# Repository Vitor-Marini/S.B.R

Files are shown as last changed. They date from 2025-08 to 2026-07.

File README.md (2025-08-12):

#S.B.R - Self Balance Robot

**Robô autoequilibrante com controle PID**

---

##  Descrição

Este projeto tem como objetivo o desenvolvimento de um robô autoequilibrante , que utiliza um controle PID para se manter estável sobre duas rodas. O sistema utiliza dados de um sensor giroscópio para calcular os ajustes de equilíbrio em tempo real.

Uma interface web interativa será servida diretamente pelo robô, permitindo visualizar os dados de controle (como ângulo, correção do PID e status do motor).

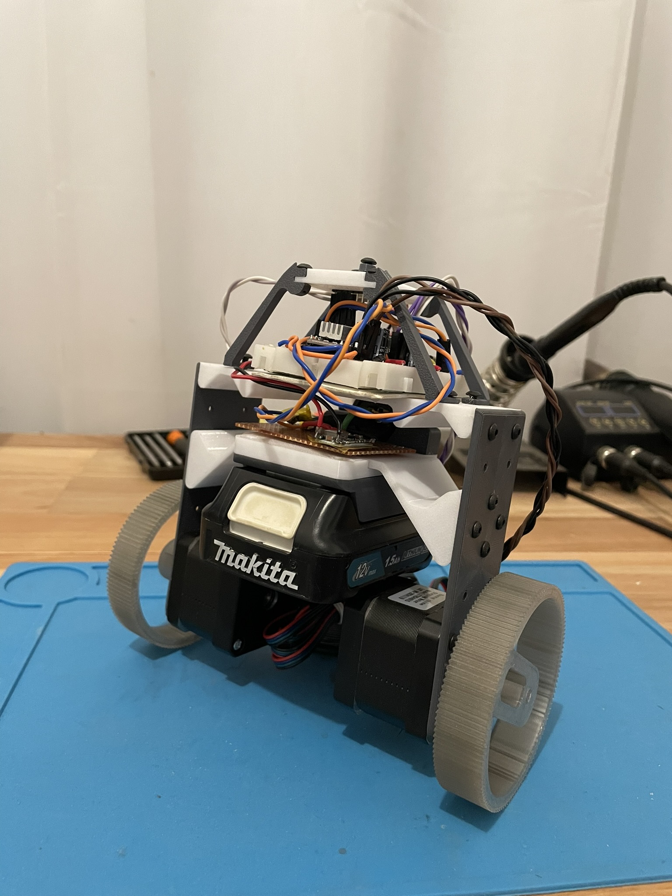
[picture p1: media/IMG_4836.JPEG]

---

## 🔧Componentes & Technologias

- **ESP32-C3 Supermini**
- **Motor de passo NEMA17 + DRV8825**
- **MPU6050 (giroscópio + acelerômetro)**
- **Bateria(12v) Makita BL1016
- **PlatformIO + C++**

- **Chassi 3D:** 
[3D models](hardware\3d-models)

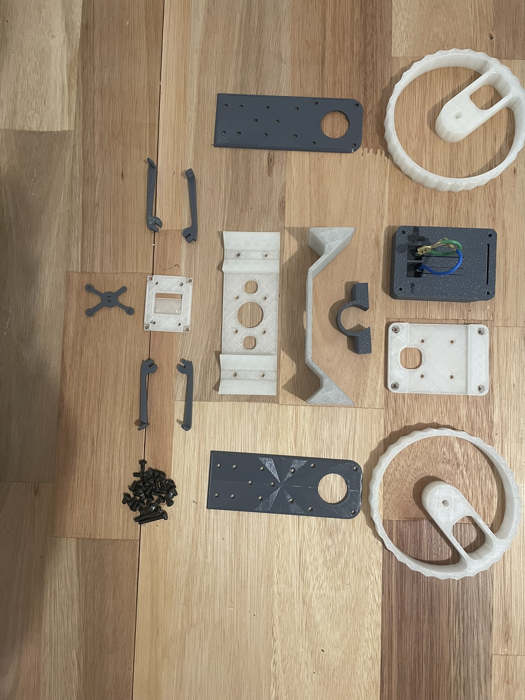
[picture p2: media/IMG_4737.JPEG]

---

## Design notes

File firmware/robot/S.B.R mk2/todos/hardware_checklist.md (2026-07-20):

# Hardware Checklist — S.B.R mk2

Tarefas físicas para preparar o robô para o novo firmware.

---

## 1. Medir o diâmetro das rodas

- [ ] Medir o diâmetro externo da roda em **milímetros**
- [ ] Anotar o valor em `config.hpp` como `WHEEL_DIAMETER_MM`
- Necessário para odometria e futura velocidade linear

---

## 2. Descobrir o microstepping dos DRV8825

Os pinos M0, M1, M2 dos drivers **não estão conectados ao ESP32-C3**.  
Eles estão configurados via jumpers/solda nos próprios módulos DRV8825.

- [ ] Inspecionar fisicamente os dois drivers DRV8825
- [ ] Verificar se há jumpers (shunts) em M0, M1, M2
- [ ] Se não houver jumpers: provavelmente **full step** (200 passos/volta)
- [ ] Anotar a configuração e o steps_per_rev resultante

Tabela de configuração típica (DRV8825):

| M2  | M1  | M0  | Microstepping | Steps/rev |
|-----|-----|-----|---|---|
| LOW | LOW | LOW | Full step | 200 |
| LOW | LOW | HIGH| 1/2 step | 400 |
| LOW | HIGH| LOW | 1/4 step | 800 |
| LOW | HIGH| HIGH| 1/8 step | 1600 |
| HIGH| LOW | LOW | 1/16 step | 3200 |
| HIGH| LOW | HIGH| 1/32 step | 6400 |

Valores típicos para jumpers abertos (sem shunt): todos LOW = **full step**.

---

## 3. Verificar ENABLE dos DRV8825

- [ ] Verificar se o pino ENABLE de cada DRV8825 está com pull-up ou pull-down
- [ ] Se pino ENABLE solto: o módulo tem pull-up interno → motor habilitado
- [ ] Se pino ENABLE conectado ao GND via resistor: motor sempre habilitado
- [ **Ideal:** Conectar ENABLE a um GPIO do ESP32-C3 para desligar motores em IDLE/FAULT

Se não for possível conectar ao ESP32, deixar ENABLE como está (sempre habilitado).

---

## 4. Definir o sentido de rotação dos motores

- [ ] Alimentar o motor esquerdo com DIR=HIGH e verificar se a roda gira para **frente** (robô anda para frente)
- [ ] Se não: anotar que o motor esquerdo precisa de DIR invertido (`MOTOR_LEFT_REVERSED = true` no config)
- [ ] Repetir para o motor direito
- [ ] Atualizar `MOTOR_LEFT_REVERSED` e `MOTOR_RIGHT_REVERSED` no `config.hpp`

---

## 5. Verificar tensão de referência dos DRV8825 (corrente do motor)

- [ ] Medir a tensão no potenciômetro de cada DRV8825 (VREF)
- [ ] A corrente máxima do motor NEMA17 é tipicamente 1.0-1.5A
- [ ] VREF ideal ≈ 0.7V a 1.2V (depende do resistor sense)
- [ ] Fórmula: I_max = VREF × 2 (para DRV8825 com resistor sense de 0.1Ω)

---

## 6. Nivelamento físico

- [ ] Verificar se o MPU6050 está montado nivelado (paralelo ao chão)
- [ ] Se não estiver nivelado, anotar o offset mecânico
- [ ] Verificar se as rodas estão bem fixas e alinhadas
- [ ] Verificar se o centro de massa está acima do eixo das rodas (ou ligeiramente atrás)

---

## 7. Bateria

- [ ] Bateria Makita BL1016 (10.8V/12V) — verificar tensão nominal
- [ ] Verificar se há divisor de tensão para monitoramento pela ADC do ESP32-C3
- [ ] Se houver, anotar os resistores do divisor (R1, R2) para configurar no firmware

---

## 8. Teste de LEDC PWM (pré-balanceamento)

Após gravar o firmware mk2 pela primeira vez:

- [ ] Conectar via Serial (115200 baud)
- [ ] Digitar `motor left 500` — o motor esquerdo deve girar a 500 steps/s
- [ ] Digitar `motor right 500` — o motor direito deve girar a 500 steps/s
- [ ] Digitar `motor left 0` — o motor esquerdo deve parar
- [ ] Verificar se o sentido está correto (usar `motor left -500` para inverter)

---

## Configuração da RoboCORE (preencher após medir)

```cpp
// Em include/config.hpp
WHEEL_DIAMETER_MM =  // <-- preencher
STEPS_PER_REV =      // <-- preencher (200 × microstepping)
MOTOR_LEFT_REVERSED  = false  // <-- ajustar se necessário
MOTOR_RIGHT_REVERSED = false  // <-- ajustar se necessário
```

---

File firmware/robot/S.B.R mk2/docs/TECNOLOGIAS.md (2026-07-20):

# Tecnologias e Técnicas — S.B.R mk2

## Controle de Motores com LEDC PWM (sem interrupções!)

No firmware original (mk1), os motores de passo eram controlados por interrupções de hardware
(timers). Cada pulso de passo gerava uma interrupção que chamava `digitalWrite()` dentro da ISR
— extremamente custoso para um microcontrolador de núcleo único (ESP32-C3).

No mk2, usamos o periférico **LEDC** (PWM) do ESP32-C3:

- Cada motor recebe um canal PWM independente
- A **frequência do PWM = steps por segundo** do motor
- Duty cycle fixo em 50% (cada borda de subida = um passo do motor)
- **Zero interrupções** — o hardware gera os pulsos sozinho
- A CPU fica livre para rodar o controle e a telemetria

```
LEDC Timer 0 ── Canal 0 ── GPIO 0 (STEP motor esquerdo)
LEDC Timer 1 ── Canal 3 ── GPIO 3 (STEP motor direito)
```

Para mudar a velocidade, basta chamar `ledc_set_freq()`. Para parar o motor,
colocamos o duty cycle em 0 (pino fica em LOW). Não há mais a sobrecarga
de interrupções a cada passo.

### Rampa de aceleração

Toda mudança de velocidade passa por um **rampeador** que limita a aceleração:

```
maxDelta = maxAccelStepsS2 × dt
current += constrain(target - current, -maxDelta, +maxDelta)
```

Isso evita que os steppers percam passos por aceleração brusca.
O valor padrão é 25000 steps/s² (0 a 6000 steps/s em ~240ms),
configurável em `config.hpp` como `motor.maxAccelStepsS2`.

---

## Filtro Mahony (fusão de sensores)

O MPU6050 tem dois sensores:

| Sensor | Bom para | Ruim para |
|---|---|---|
| Acelerômetro | Saber onde é "pra baixo" (gravidade) | Ruído alto, não responde rápido |
| Giroscópio | Medir rotação rápida com precisão | Deriva com o tempo (drift) |

O **Filtro Mahony** combina o melhor dos dois:

1. Mede o ângulo pelo acelerômetro (referência de gravidade)
2. Estima o ângulo pelo giroscópio (resposta rápida)
3. Calcula o erro entre os dois
4. Usa esse erro para corrigir o giroscópio (estimando o bias/deriva)
5. Integra o giroscópio corrigido para obter o ângulo final

O resultado é um ângulo de pitch preciso e com baixo atraso, essencial para o
equilíbrio. O filtro também estima automaticamente o bias do girospcópio
enquanto o robô opera, eliminando a necessidade de recalibração constante.

### Parâmetros do filtro

- **Mahony Kp** (0.5): velocidade com que o filtro corrige o ângulo usando o
  acelerômetro. Maior = resposta mais rápida, mas mais ruído.
- **Mahony Ki** (0.001): velocidade com que o filtro aprende o bias do
  giroscópio. Muito alto pode causar oscilações.

Configuráveis em `config.hpp` como `filter.mahonyKp` e `filter.mahonyKi`.

### Filtro Complementar (fallback)

Se o Mahony se mostrar pesado demais, o firmware também tem um
**Filtro Complementar** clássico:

```
ângulo = α × (ângulo + gyro × dt) + (1 − α) × accelAngle
```

O alpha padrão é 0.98 (98% giroscópio, 2% acelerômetro).
Pode ser ativado via `imu.setUseMahony(false)`.

---

## PID Cascateado (três níveis de controle)

O controle de equilíbrio usa três malhas aninhadas, cada uma rodando em uma
frequência diferente:

```
┌─────────────────────────────────────────────────────┐
│                    Malha de Yaw                       │
│  (heading-hold) mantém o robô apontando na direção   │
│  yaw_correção = Kp_y × erro_yaw + Kd_y × (-yaw_rate) │
└─────────────────────┬───────────────────────────────┘
                      │ comando diferencial
                      ▼
┌─────────────────────────────────────────────────────┐
│                  Malha de Ângulo                      │
│  (equilíbrio) mantém o robô na vertical              │
│  torque = Kp_a × erro_angulo + Kd_a × (-pitch_rate)  │
└─────────────────────┬───────────────────────────────┘
                      │ torque total
                      ▼
┌─────────────────────────────────────────────────────┐
│              Distribuição para os Motores             │
│  motor_esquerdo = torque + yaw_correção              │
│  motor_direito  = torque − yaw_correção              │
└─────────────────────────────────────────────────────┘
```

### 1. Malha de Ângulo (100 Hz)

- **Entrada**: pitch do filtro Mahony + pitch rate do giroscópio
- **Saída**: torque (0 a 100%)
- **Controle**: PD com derivativo do gyro (não do ângulo)

```
torque = Kp × (setpoint − pitch) + Kd × (−pitch_rate)
```

Usar o gyro rate direto no termo derivativo elimina o ruído amplificado
que aconteceria ao derivar o ângulo.

Padrões: Kp = 25.0, Ki = 0.5, Kd = 0.8

### 2. Malha de Yaw (100 Hz)

- **Entrada**: yaw estimado pelo Mahony + yaw rate do giroscópio
- **Saída**: correção diferencial (−30 a +30%)
- **Controle**: PID

Mantém o robô apontando na mesma direção (heading-hold).
O erro de yaw é normalizado para ±180° para evitar saltos no controle.

Padrões: Kp = 2.0, Ki = 0.02, Kd = 0.5

### 3. Malha de Velocidade (futuro — implementação parcial)

Preparada para o "andar". Quando ativada:
- Entrada: odometria (contagem de passos)
- Saída: setpoint de ângulo (inclinar para frente = andar para frente)

O controle de velocidade ainda não está ativo — os placeholders existem
no `config.hpp` como `velocityPid` para quando você quiser implementar.

---

## Odometria (contagem de passos)

Cada motor tem um contador de passos acumulados:

```cpp
_leftSteps += (int32_t)(currentSpeedL × dt);
_rightSteps += (int32_t)(currentSpeedR × dt);
```

A partir disso, podemos calcular:
- **Distância percorrida**: `passos / stepsPorVolta × π × diametroRoda`
- **Velocidade linear**: derivada da distância
- **Rotação do robô**: diferença entre as rodas

A odometria é usada no controle de velocidade (futuro) e pode ser visualizada
no CLI com o comando `status`. Use `reset` para zerar os contadores.

**ATENÇÃO**: A odometria com steppers sem encoder é estimada — se o motor
perder passos (situação de stall), a contagem fica incorreta.

---

## Máquina de Estados (Supervisor)

O robô não tenta mais equilibrar imediatamente ao ligar. Agora ele segue
uma máquina de estados:

```
INIT ──→ CALIBRATE ──→ IDLE ──→ STARTING ──→ ACTIVE ──→ MOVING
                           ↑                        │
                           └──── FAULT ←────────────┘
```

| Estado | O que acontece |
|---|---|
| **INIT** | Inicializa MPU6050, configura filtros |
| **CALIBRATE** | Calibra o giroscópio (500 amostras, robô parado) |
| **IDLE** | Robô parado, WiFi ligado, só monitora ângulo |
| **STARTING** | Rampa de 2s: ganhos do PID crescem de 0 a 100% |
| **ACTIVE** | Equilíbrio ativo + heading-hold |
| **MOVING** | ACTIVE + controle de velocidade (futuro) |
| **FAULT** | Ângulo > 45°, motores desligados. Auto-recovery após 3s estável |

Isso evita que o robô "saia disparado" ao ligar e permite recuperação
automática de quedas.

---

## CLI (Terminal Interativo)

O terminal serial agora aceita comandos:

| Comando | Função |
|---|---|
| `start` | Inicia o balanceamento |
| `stop` | Para e volta a IDLE |
| `calibrate` | Recalibra o giroscópio |
| `status` | Mostra todos os parâmetros |
| `tune kp 30` | Ajusta Kp do ângulo em tempo real |
| `tune ykp 3` | Ajusta Kp do yaw |
| `tune sp 1` | Muda o setpoint (inclinação alvo) |
| `motor left 500` | Gira motor esquerdo a 500 steps/s |
| `motor right -300` | Gira motor direito ao contrário |
| `angle` | Mostra ângulo atual |
| `save` / `load` | Salva/carrega config na flash |
| `reset` | Zera odometria e integrais |

---

## Dashboard Web (WiFi + WebSocket)

O robô cria uma rede WiFi (`SBR_ROBOT`, senha `12345678`).

O dashboard web (`192.168.4.1`) mostra em tempo real:
- **Gráfico do ângulo** (Chart.js, últimos 100 pontos)
- **Estado atual** do robô (ACTIVE, FAULT, etc)
- Telemetria: pitch, rate, yaw, output do PID, velocidades
- **Sliders** para ajustar Kp, Ki, Kd, setpoint
- **Botões**: INICIAR, PARAR, CALIBRAR
- **Exportar CSV** dos dados de ângulo

A comunicação é via WebSocket — os dados do PID e telemetria são enviados
a ~10 Hz.

---

## MPU6050 — Configuração

| Parâmetro | Mk1 | Mk2 |
|---|-----|-----|
| Range acelerômetro | ±8G | ±8G |
| Range giroscópio | ±500°/s | ±500°/s |
| **DLPF (filtro hardware)** | **5 Hz** | **44 Hz** |

O DLPF de 5Hz no mk1 adicionava ~40ms de atraso na leitura, o que
desestabilizava o controle. No mk2, subimos para 44Hz e deixamos o
filtro Mahony cuidar do ruído restante — resposta muito mais rápida.

---

## Componentes e Pinagem

```
ESP32-C3 Supermini
├── GPIO 0  → STEP motor L (LEDC Canal 0)
├── GPIO 1  → DIR motor L
├── GPIO 2  → DIR motor R
├── GPIO 3  → STEP motor R (LEDC Canal 3)
├── GPIO 8  → SDA (MPU6050)
└── GPIO 9  → SCL (MPU6050)
```

Os pinos M0, M1, M2 (microstepping) e ENABLE dos DRV8825 não estão
conectados ao ESP32. O microstepping é definido por jumpers nos próprios
módulos. **Verifique a configuração atual** (provavelmente full step).

---

## Resumo das melhorias do mk1 para o mk2

| Problema no mk1 | Solução no mk2 |
|---|---|
| Stepper via ISR com digitalWrite (lento) | LEDC PWM sem interrupção |
| dt fixo de 10ms | dt medido em tempo real |
| Filtro complementar | Mahony com estimativa de bias |
| Sem controle de yaw | Heading-hold com PID |
| Inicialização abrupta | Máquina de estados com rampa |
| MPU6050 DLPF em 5Hz (lento) | DLPF em 44Hz |
| Ki = 0 (sem integral) | Ki = 0.5 com anti-windup |
| Só log serial | CLI interativo com comandos |
| Debug só por Serial | Dashboard Web + Serial CLI |

---

## Configuração Inicial (após montagem)

Antes de tentar equilibrar, complete os passos em
[`todos/hardware_checklist.md`](../todos/hardware_checklist.md):

1. Medir diâmetro das rodas → `wheel_diameter_mm`
2. Verificar microstepping → `steps_per_rev`
3. Testar sentido dos motores via CLI → `left_reversed` / `right_reversed`
4. Com `start`, observar se o robô tenta se equilibrar
5. Ajustar Kp, Ki, Kd pelos sliders do dashboard ou CLI (`tune`)

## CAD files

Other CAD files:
hardware/3d-models/CHASSI_Pcb_SHELF.f3d
hardware/3d-models/CHASSI_PowerSwitch_HOLDER.f3d
hardware/3d-models/CHASSI_SideFrame_LEFT.f3d
hardware/3d-models/CHASSI_SideFrame_RIGHT.f3d
hardware/3d-models/CHASSI_mpu_HOLDER.f3d
hardware/3d-models/LINK-SHELF-to-B_ADPTOR.f3d
hardware/3d-models/Wheel Big.f3d
hardware/3d-models/Whell Medium.f3d
hardware/3d-models/makita_10.8v_v38 v10.f3d

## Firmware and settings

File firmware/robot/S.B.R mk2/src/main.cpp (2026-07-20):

#include <Arduino.h>
#include "config.hpp"
#include "motor.hpp"
#include "imu_manager.hpp"
#include "balance.hpp"
#include "supervisor.hpp"
#include "web_interface.hpp"
#include "cli.hpp"

void setup() {
    Serial.begin(115200);
    delay(500);
    Serial.println("\n\n=== S.B.R mk2 ===");

    cfg.begin();

    motors.begin();

    supervisor.begin();

    web.begin();

    cli.begin();
}

void loop() {
    supervisor.run();

    web.broadcast();

    cli.update();

    delay(1);
}

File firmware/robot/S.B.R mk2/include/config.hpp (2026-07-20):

#ifndef CONFIG_HPP
#define CONFIG_HPP

#include <Arduino.h>

struct PIDGains {
    float kp;
    float ki;
    float kd;
};

struct MotorParams {
    float stepsPerRev = 3200.0f;
    float wheelDiameterMm = 80.0f;
    float maxAccelStepsS2 = 25000.0f;
    bool leftReversed = false;
    bool rightReversed = false;
};

struct FilterParams {
    float mahonyKp = 0.5f;
    float mahonyKi = 0.001f;
    float complementaryAlpha = 0.98f;
};

class ConfigManager {
public:
    void begin();

    PIDGains anglePid{25.0f, 0.5f, 0.8f};
    PIDGains velocityPid{0.5f, 0.1f, 0.0f};
    PIDGains yawPid{2.0f, 0.02f, 0.5f};

    MotorParams motor;
    FilterParams filter;

    float setpoint = 0.0f;
    float failsafeAngle = 45.0f;

    float pitchAngle = 0.0f;
    float pitchRate = 0.0f;
    float yawAngle = 0.0f;
    float yawRate = 0.0f;
    float pidOutput = 0.0f;
    float leftSpeed = 0.0f;
    float rightSpeed = 0.0f;
    int robotState = 0;

    bool load();
    bool save();
    void print();
};

extern ConfigManager cfg;
#endif

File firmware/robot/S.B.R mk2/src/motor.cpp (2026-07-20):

#include "motor.hpp"
#include "config.hpp"
#include <driver/ledc.h>
#include <math.h>

MotorManager motors;

void MotorManager::begin() {
    pinMode(PIN_DIR_L, OUTPUT);
    pinMode(PIN_DIR_R, OUTPUT);
    digitalWrite(PIN_DIR_L, LOW);
    digitalWrite(PIN_DIR_R, LOW);

    ledc_timer_config_t tL = {
        .speed_mode = LEDC_LOW_SPEED_MODE,
        .duty_resolution = LEDC_TIMER_10_BIT,
        .timer_num = (ledc_timer_t)LEDC_TIM_L,
        .freq_hz = 1000,
        .clk_cfg = LEDC_AUTO_CLK
    };
    ledc_timer_config(&tL);

    ledc_timer_config_t tR = {
        .speed_mode = LEDC_LOW_SPEED_MODE,
        .duty_resolution = LEDC_TIMER_10_BIT,
        .timer_num = (ledc_timer_t)LEDC_TIM_R,
        .freq_hz = 1000,
        .clk_cfg = LEDC_AUTO_CLK
    };
    ledc_timer_config(&tR);

    ledc_channel_config_t chL = {
        .gpio_num = PIN_STEP_L,
        .speed_mode = LEDC_LOW_SPEED_MODE,
        .channel = (ledc_channel_t)LEDC_CH_L,
        .timer_sel = (ledc_timer_t)LEDC_TIM_L,
        .duty = 512,
        .hpoint = 0
    };
    ledc_channel_config(&chL);

    ledc_channel_config_t chR = {
        .gpio_num = PIN_STEP_R,
        .speed_mode = LEDC_LOW_SPEED_MODE,
        .channel = (ledc_channel_t)LEDC_CH_R,
        .timer_sel = (ledc_timer_t)LEDC_TIM_R,
        .duty = 512,
        .hpoint = 0
    };
    ledc_channel_config(&chR);

    ledc_set_freq(LEDC_LOW_SPEED_MODE, (ledc_timer_t)LEDC_TIM_L, 1);
    ledc_set_freq(LEDC_LOW_SPEED_MODE, (ledc_timer_t)LEDC_TIM_R, 1);

    _lastUpdate = millis();

    Serial.println("Motores inicializados (LEDC PWM).");
}

void MotorManager::_setChannelFreq(int timer, int channel, int pin, float stepsPerSec) {
    int freq = (int)(stepsPerSec + 0.5f);
    if (freq < 1) freq = 1;
    if (freq > 50000) freq = 50000;

    ledc_set_freq(LEDC_LOW_SPEED_MODE, (ledc_timer_t)timer, freq);
}

void MotorManager::_stopChannel(int channel, int pin) {
    ledc_set_duty(LEDC_LOW_SPEED_MODE, (ledc_channel_t)channel, 0);
    ledc_update_duty(LEDC_LOW_SPEED_MODE, (ledc_channel_t)channel);
}

void MotorManager::_rampMotor(float target, float& current, float maxDelta) {
    float delta = target - current;
    if (fabsf(delta) <= maxDelta) {
        current = target;
    } else {
        current += (delta > 0.0f) ? maxDelta : -maxDelta;
    }
}

void MotorManager::setSpeeds(float left, float right) {
    uint32_t now = millis();
    float dt = (now - _lastUpdate) / 1000.0f;
    if (dt > 0.1f || dt <= 0.0f) dt = 0.01f;
    _lastUpdate = now;

    int dirL = (left >= 0) ? HIGH : LOW;
    int dirR = (right >= 0) ? HIGH : LOW;

    if (cfg.motor.leftReversed) dirL = (dirL == HIGH) ? LOW : HIGH;
    if (cfg.motor.rightReversed) dirR = (dirR == HIGH) ? LOW : HIGH;

    digitalWrite(PIN_DIR_L, dirL);
    digitalWrite(PIN_DIR_R, dirR);

    float absL = fabsf(left);
    float absR = fabsf(right);

    float maxDelta = cfg.motor.maxAccelStepsS2 * dt;

    float targetL = absL;
    float targetR = absR;

    if (left == 0.0f && right == 0.0f) {
        _currentL = 0.0f;
        _currentR = 0.0f;
    } else {
        _rampMotor(targetL, _currentL, maxDelta);
        _rampMotor(targetR, _currentR, maxDelta);
    }

    if (_currentL < 10.0f) {
        ledc_set_duty(LEDC_LOW_SPEED_MODE, (ledc_channel_t)LEDC_CH_L, 0);
        ledc_update_duty(LEDC_LOW_SPEED_MODE, (ledc_channel_t)LEDC_CH_L);
    } else {
        ledc_set_duty(LEDC_LOW_SPEED_MODE, (ledc_channel_t)LEDC_CH_L, 512);
        ledc_update_duty(LEDC_LOW_SPEED_MODE, (ledc_channel_t)LEDC_CH_L);
        _setChannelFreq(LEDC_TIM_L, LEDC_CH_L, PIN_STEP_L, _currentL);
    }

    if (_currentR < 10.0f) {
        ledc_set_duty(LEDC_LOW_SPEED_MODE, (ledc_channel_t)LEDC_CH_R, 0);
        ledc_update_duty(LEDC_LOW_SPEED_MODE, (ledc_channel_t)LEDC_CH_R);
    } else {
        ledc_set_duty(LEDC_LOW_SPEED_MODE, (ledc_channel_t)LEDC_CH_R, 512);
        ledc_update_duty(LEDC_LOW_SPEED_MODE, (ledc_channel_t)LEDC_CH_R);
        _setChannelFreq(LEDC_TIM_R, LEDC_CH_R, PIN_STEP_R, _currentR);
    }

    _leftSteps += (int32_t)(_currentL * dt);
    _rightSteps += (int32_t)(_currentR * dt);

    cfg.leftSpeed = (dirL == HIGH) ? _currentL : -_currentL;
    cfg.rightSpeed = (dirR == HIGH) ? _currentR : -_currentR;
}

void MotorManager::stop() {
    _currentL = 0.0f;
    _currentR = 0.0f;
    ledc_set_duty(LEDC_LOW_SPEED_MODE, (ledc_channel_t)LEDC_CH_L, 0);
    ledc_update_duty(LEDC_LOW_SPEED_MODE, (ledc_channel_t)LEDC_CH_L);
    ledc_set_duty(LEDC_LOW_SPEED_MODE, (ledc_channel_t)LEDC_CH_R, 0);
    ledc_update_duty(LEDC_LOW_SPEED_MODE, (ledc_channel_t)LEDC_CH_R);
}

void MotorManager::enable() {
    stop();
}

void MotorManager::disable() {
    stop();
}

void MotorManager::resetOdometry() {
    _leftSteps = 0;
    _rightSteps = 0;
}

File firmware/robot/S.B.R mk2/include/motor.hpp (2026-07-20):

#ifndef MOTOR_HPP
#define MOTOR_HPP

#include <Arduino.h>

class MotorManager {
public:
    void begin();
    void setSpeeds(float leftSteps, float rightSteps);
    void stop();
    void enable();
    void disable();

    int32_t getLeftSteps() { return _leftSteps; }
    int32_t getRightSteps() { return _rightSteps; }
    void resetOdometry();

private:
    static const int PIN_STEP_L = 0;
    static const int PIN_DIR_L  = 1;
    static const int PIN_DIR_R  = 2;
    static const int PIN_STEP_R = 3;

    static const int LEDC_CH_L = 0;
    static const int LEDC_CH_R = 3;
    static const int LEDC_TIM_L = 0;
    static const int LEDC_TIM_R = 1;
    static const int LEDC_RES = 10;

    float _targetL = 0.0f, _targetR = 0.0f;
    float _currentL = 0.0f, _currentR = 0.0f;
    int32_t _leftSteps = 0, _rightSteps = 0;
    uint32_t _lastUpdate = 0;

    void _setChannelFreq(int timer, int channel, int pin, float stepsPerSec);
    void _stopChannel(int channel, int pin);
    void _rampMotor(float target, float& current, float maxDelta);
};

extern MotorManager motors;
#endif

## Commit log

2025-06-20 test(hardware) :Add test code for mpu and stepper
2025-08-04 feat(system): implement base logic for self-balancing robot
    - Add MPU6050 reading module
    - Integrate motor control using DRV8825
    - Implement basic PID control loop
    - Structure code in modular classes
2025-08-05 update mpu , pid changes
2025-08-12 update repo organization
    [CHASSI_Pcb_SHELF.f3d, CHASSI_PowerSwitch_HOLDER.f3d, CHASSI_SideFrame_LEFT.f3d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]
2026-03-06 feat: sensor fusion| feat: added more control with timers
